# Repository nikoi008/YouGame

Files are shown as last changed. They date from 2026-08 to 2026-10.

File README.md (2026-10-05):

# YouGame!

## What is it? 
YouGame is a handheld device designed for making games using the tft adruino library!

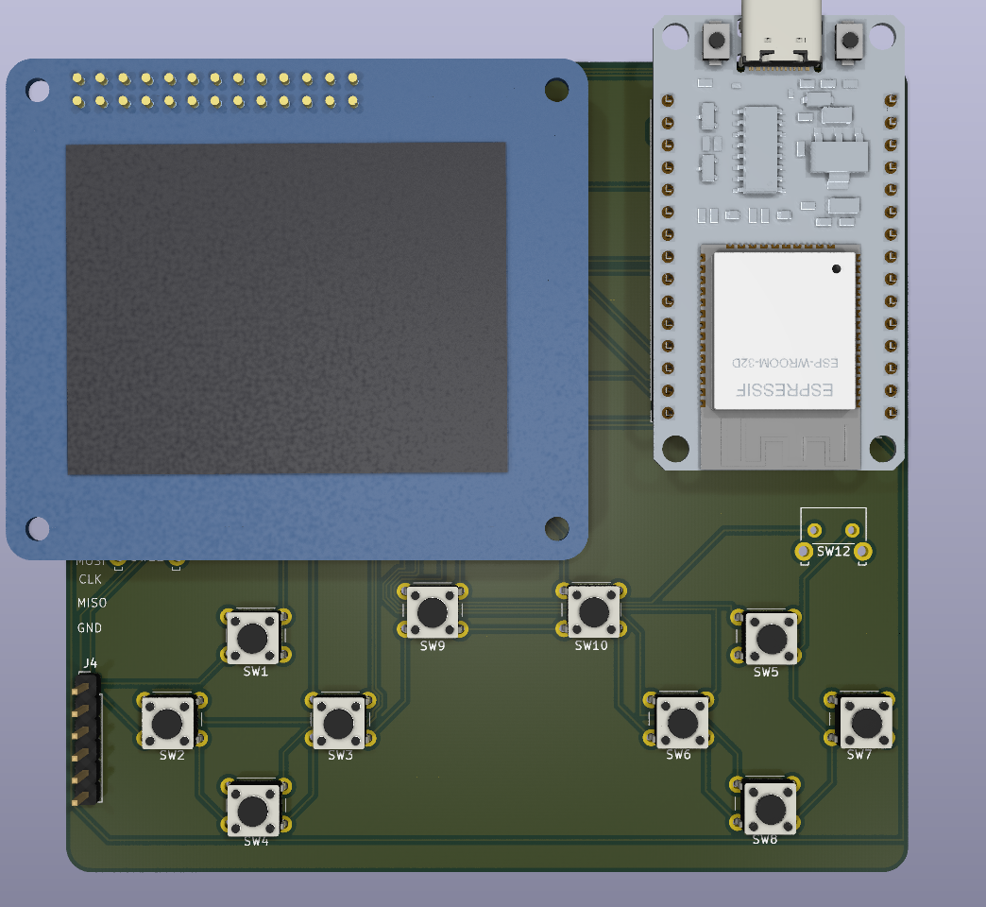
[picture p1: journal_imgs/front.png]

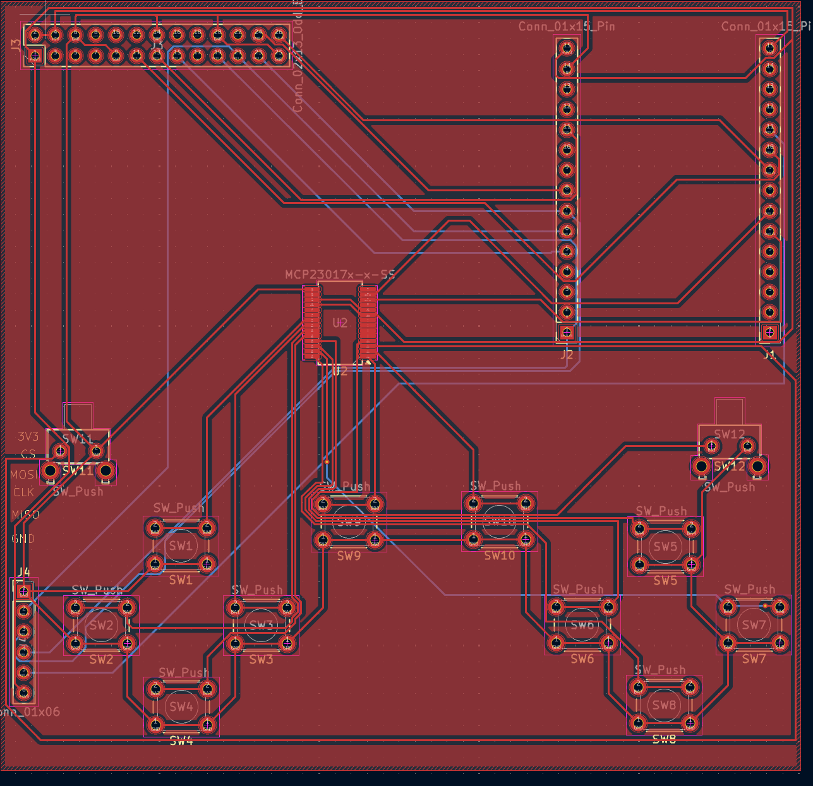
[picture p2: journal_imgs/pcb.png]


## Features
12 Buttons -- 10 normal push buttons and 2 shoulder trigger style buttons  
320x240 LCD screen  
SD card slot to store the games on an sd card  
ESP32 S3 as the brains  

## Why was this made?  
I mainly decided to do this since I had an old raspberry pi screen that i thought was fried. Since i didn't have my pi on me, I decided to use my esp32 to see if it was. After a while of figuring out which pin goes where, i finally managed to turn on the backlight, and then got images displaying on it! After that i had the idea to turn it into something more than just making it work, so I decided to use it for my second ever hardware project. Along the way I figured out how to use SD card modules, used an expansion board which connects all the buttons together, and learned a lot about hardware all together!  

## Building instructions

Its easiest to start with smallest first, so here is how it will go.  

### Sd card module and triggers
The sd card module and the triggers are going to be under the board, so make sure they are connected the right way round

### MCP2017 Expansion board
Get your soldering iron out because thisll have to be hand soldered

### Headers and buttons  
Headers and buttons are all through hole components so it shouldn't be too challenging to solder them through
## BOM

| Item | Qty | Price (USD) | Link |
|---|---|---|---|
| 2.4" Touch Screen SPI TFT LCD | 1 | $10.24 | [Link](https://www.aliexpress.com/item/1005005770033042.html) |
|2x40 Breakable Pin Header 2.54mm Male (10pcs) | 1 | $2.05 | [Link](https://a.aliexpress.com/_EJZPzXy) |
| Momentary Tactile Push Button 6x6x5 Right Angle (20pcs) | 1 | $1.74 | [Link](https://www.aliexpress.com/item/1005006384754591.html) |
| 12x12mm Panel Tactile Switch, H6.5mm (10pcs) — shoulder buttons | 1 | $1.60 | [Link](https://www.aliexpress.com/item/1005006164609617.html) |
| TF Micro SD Card Module (SPI) | 1 | $0.90 | [Link](https://www.aliexpress.com/item/1005005302035188.html) |
| Female Pin Header Socket Gold Plated 15-Pin (10pcs) | 1 | $3.70 | [Link](https://www.aliexpress.com/item/1005003610333849.html) |
| ESP32 WiFi Bluetooth Dev Board Type-C CH340 | 1 | $5.59 | [Link](https://www.aliexpress.com/item/1005008771142129.html) |
| PCB fabrication | 1 | $11.45 | jlcbcp.com  |
| MCP2017-SS expansion baord | 1 | 1.84 | https://www.aliexpress.com/item/1005010450787157.html?mp=1 |

**Total:** $39.1

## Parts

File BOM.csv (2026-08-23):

Item | Qty | Price (USD) | Link
2.4" Touch Screen SPI TFT LCD | 1 | $10.24 | https://www.aliexpress.com/item/1005005770033042.html
2x40 Breakable Pin Header 2.54mm Male (10pcs) | 1 | $2.05 | https://a.aliexpress.com/_EJZPzXy
Momentary Tactile Push Button 6x6x5 Right Angle (20pcs) | 1 | $1.74 | https://www.aliexpress.com/item/1005006384754591.html
12x12mm Panel Tactile Switch, H6.5mm (10pcs) — shoulder buttons | 1 | $1.60 | https://www.aliexpress.com/item/1005006164609617.html
TF Micro SD Card Module (SPI) | 1 | $0.90 | https://www.aliexpress.com/item/1005005302035188.html
Female Pin Header Socket Gold Plated 15-Pin (10pcs) | 1 | $3.70 | https://www.aliexpress.com/item/1005003610333849.html
ESP32 WiFi Bluetooth Dev Board Type-C CH340 | 1 | $5.59 | https://www.aliexpress.com/item/1005008771142129.html
PCB fabrication | 1 | $9.03 | jlcbcp.com

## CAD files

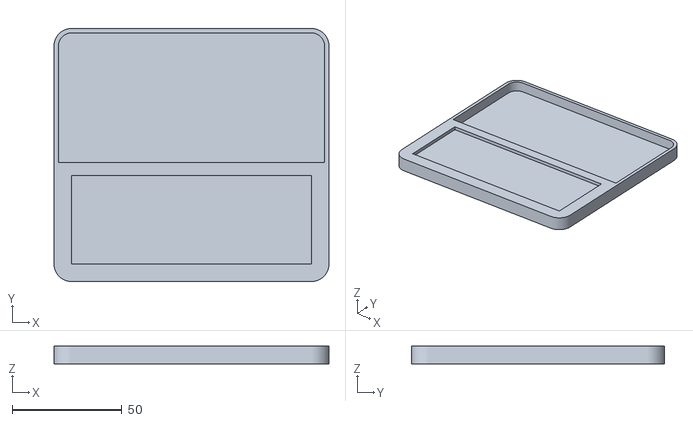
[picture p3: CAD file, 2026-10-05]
3d models/CASE.stl
125.0 x 115.0 x 8.00

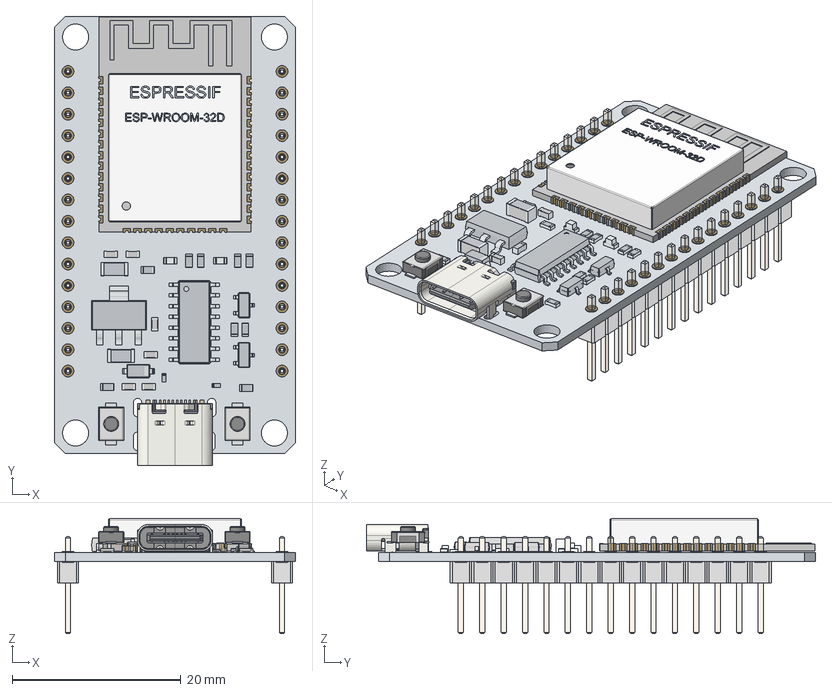
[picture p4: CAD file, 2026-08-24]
pcb/esp32.step
28.6 x 53.3 x 13.7 mm
PCB
SOIC_16_39x99mm_P127mm
SOT_223
USB_C_Receptacle_16P_TopMnt_Horizontal_GCT_USB4105-xx-A
USB_C_Receptacle_16P_TopMnt_Horizontal_GCT_USB4105-xx-A001
USB_C_Receptacle_16P_TopMnt_Horizontal_GCT_USB4105-xx-A002
USB_C_Receptacle_16P_TopMnt_Horizontal_GCT_USB4105-xx-A003
USB_C_Receptacle_16P_TopMnt_Horizontal_GCT_USB4105-xx-A004
USB_C_Receptacle_16P_TopMnt_Horizontal_GCT_USB4105-xx-A005
USB_C_Receptacle_16P_TopMnt_Horizontal_GCT_USB4105-xx-A006
USB_C_Receptacle_16P_TopMnt_Horizontal_GCT_USB4105-xx-A007
USB_C_Receptacle_16P_TopMnt_Horizontal_GCT_USB4105-xx-A008
USB_C_Receptacle_16P_TopMnt_Horizontal_GCT_USB4105-xx-A009
USB_C_Receptacle_16P_TopMnt_Horizontal_GCT_USB4105-xx-A010
USB_C_Receptacle_16P_TopMnt_Horizontal_GCT_USB4105-xx-A011
USB_C_Receptacle_16P_TopMnt_Horizontal_GCT_USB4105-xx-A012
USB_C_Receptacle_16P_TopMnt_Horizontal_GCT_USB4105-xx-A013
USB_C_Receptacle_16P_TopMnt_Horizontal_GCT_USB4105-xx-A014
USB_C_Receptacle_16P_TopMnt_Horizontal_GCT_USB4105-xx-A015
USB_C_Receptacle_16P_TopMnt_Horizontal_GCT_USB4105-xx-A016
USB_C_Receptacle_16P_TopMnt_Horizontal_GCT_USB4105-xx-A017
USB_C_Receptacle_16P_TopMnt_Horizontal_GCT_USB4105-xx-A018
USB_C_Receptacle_16P_TopMnt_Horizontal_GCT_USB4105-xx-A019
USB_C_Receptacle_16P_TopMnt_Horizontal_GCT_USB4105-xx-A020
USB_C_Receptacle_16P_TopMnt_Horizontal_GCT_USB4105-xx-A021
USB_C_Receptacle_16P_TopMnt_Horizontal_GCT_USB4105-xx-A022
USB_C_Receptacle_16P_TopMnt_Horizontal_GCT_USB4105-xx-A023
USB_C_Receptacle_16P_TopMnt_Horizontal_GCT_USB4105-xx-A024
USB_C_Receptacle_16P_TopMnt_Horizontal_GCT_USB4105-xx-A025
USB_C_Receptacle_16P_TopMnt_Horizontal_GCT_USB4105-xx-A026
USB_C_Receptacle_16P_TopMnt_Horizontal_GCT_USB4105-xx-A027
USB_C_Receptacle_16P_TopMnt_Horizontal_GCT_USB4105-xx-A028
USB_C_Receptacle_16P_TopMnt_Horizontal_GCT_USB4105-xx-A029
USB_C_Receptacle_16P_TopMnt_Horizontal_GCT_USB4105-xx-A030
USB_C_Receptacle_16P_TopMnt_Horizontal_GCT_USB4105-xx-A031
USB_C_Receptacle_16P_TopMnt_Horizontal_GCT_USB4105-xx-A032
USB_C_Receptacle_16P_TopMnt_Horizontal_GCT_USB4105-xx-A033
USB_C_Receptacle_16P_TopMnt_Horizontal_GCT_USB4105-xx-A034
USB_C_Receptacle_16P_TopMnt_Horizontal_GCT_USB4105-xx-A035
LED_0603_D2
LED_0603_PWR
SOT_23_1
SOT_23_002
D_SOD_123
R_0603_
R_0603_001
R_0603_002
R_0603_003
R_0603_004
R_0603_005
R_0603_006
R_0603_007
R_0402_001
R_0402_002
R_0603_008
C_0603_
C_0603_001
C_0603_002
C_0603_003
C_0603_004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

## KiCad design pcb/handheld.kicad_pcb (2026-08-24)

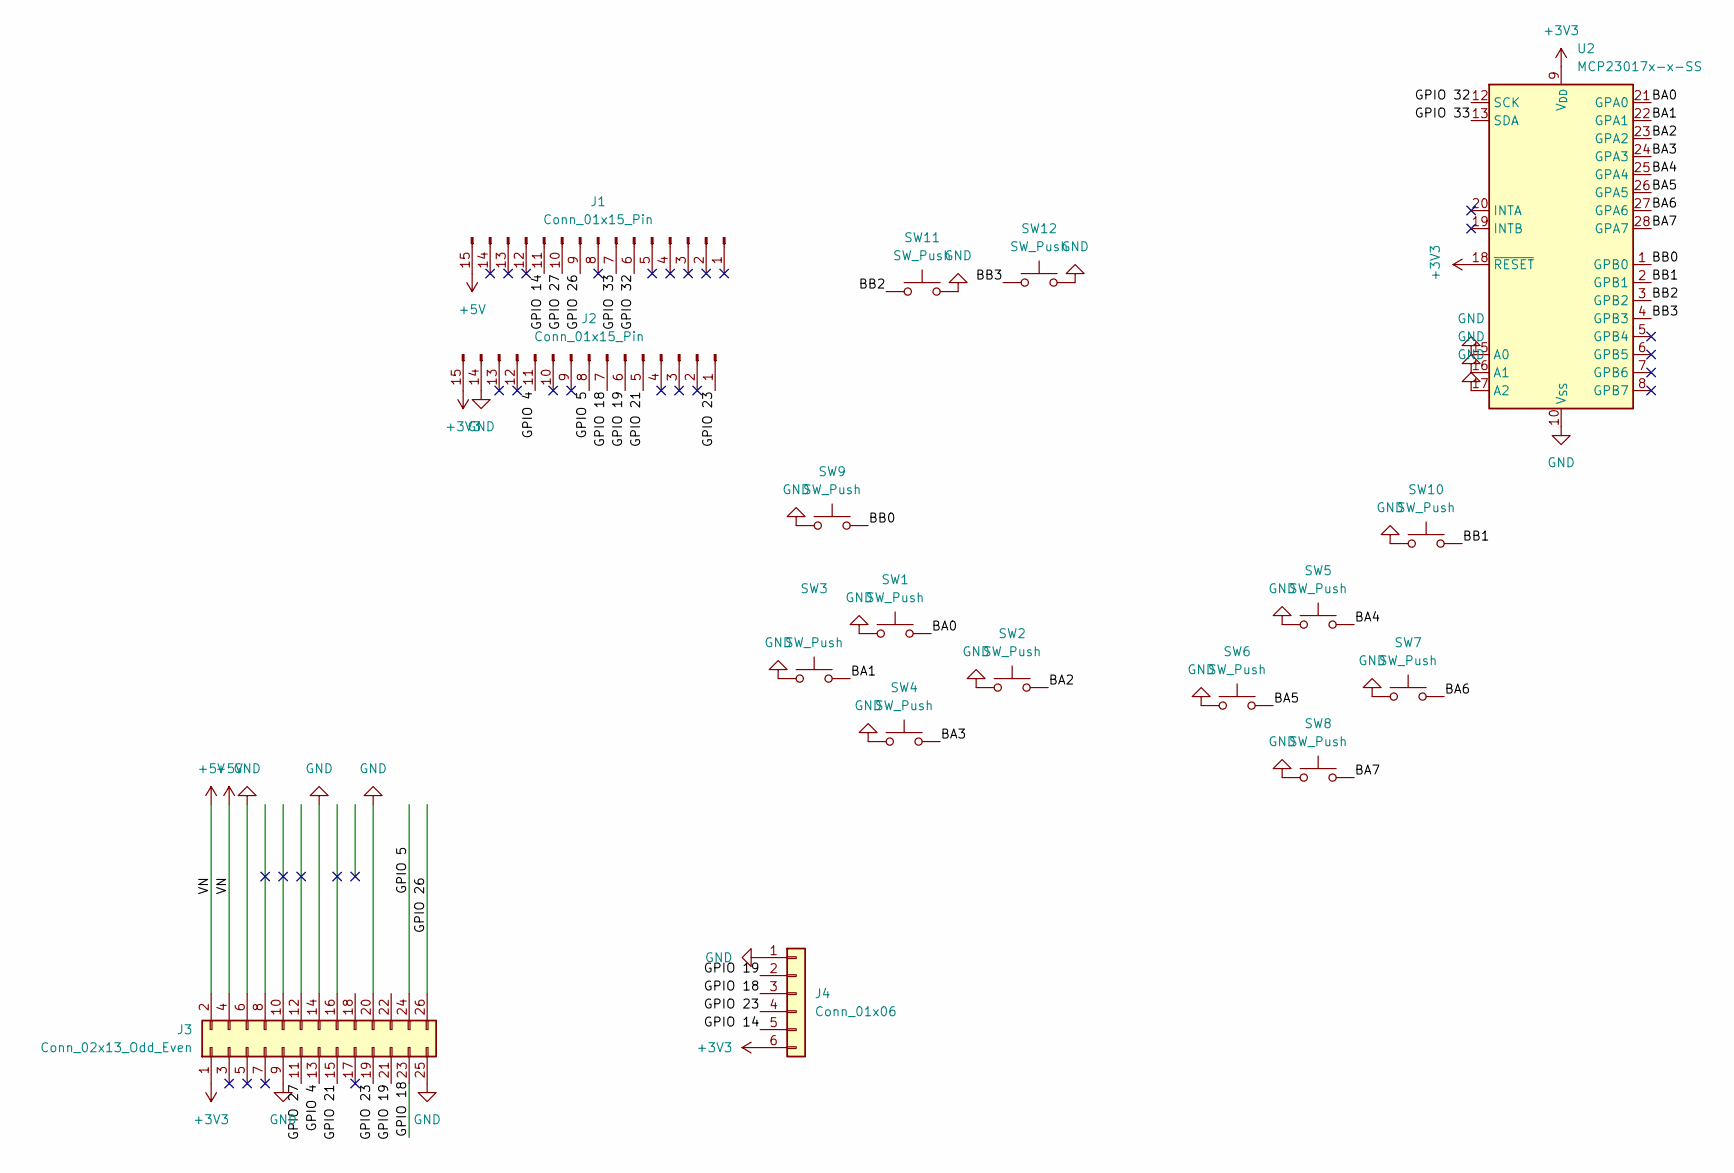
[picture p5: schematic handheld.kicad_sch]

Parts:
J1, J2: Conn_01x15_Pin; PinSocket_1x15_P2.54mm_Vertical
J3: Conn_02x13_Odd_Even; PinHeader_2x13_P2.54mm_Vertical
J4: Conn_01x06; PinHeader_1x06_P2.54mm_Vertical
SW1, SW2, SW3, SW4, SW5, SW6, SW7, SW8, SW9, SW10: SW_Push; SW_PUSH_6mm
SW11, SW12: SW_Push; SW_Tactile_SKHH_Angled
U2: MCP23017x-x-SS; SSOP-28_5.3x10.2mm_P0.65mm

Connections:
+3V3: J2.15, J3.1, J4.6, U2.9 (V_{DD}), U2.18 (~RESET)
+5V: J1.15, J3.2, J3.4
/BA0: SW1.2, U2.21 (GPA0)
/BA1: SW3.2, U2.22 (GPA1)
/BA2: SW2.2, U2.23 (GPA2)
/BA3: SW4.2, U2.24 (GPA3)
/BA4: SW5.2, U2.25 (GPA4)
/BA5: SW6.2, U2.26 (GPA5)
/BA6: SW7.2, U2.27 (GPA6)
/BA7: SW8.2, U2.28 (GPA7)
/BB0: SW9.2, U2.1 (GPB0)
/BB1: SW10.2, U2.2 (GPB1)
/BB2: SW11.1, U2.3 (GPB2)
/BB3: SW12.1, U2.4 (GPB3)
/GPIO 4: J2.11, J3.13
/GPIO 5: J2.8, J3.24
/GPIO 14: J1.11, J4.5
/GPIO 18: J2.7, J3.23, J4.3
/GPIO 19: J2.6, J3.21, J4.2
/GPIO 21: J2.5, J3.15
/GPIO 23: J2.1, J3.19, J4.4
/GPIO 26: J1.9, J3.26
/GPIO 27: J1.10, J3.11
/GPIO 32: J1.6, U2.12 (SCK)
/GPIO 33: J1.7, U2.13 (SDA)
GND: J2.14, J3.6, J3.9, J3.14, J3.20, J3.25, J4.1, SW1.1, SW2.1, SW3.1, SW4.1, SW5.1, SW6.1, SW7.1, SW8.1, SW9.1, SW10.1, SW11.2, SW12.2, U2.10 (V_{SS}), U2.15 (A0), U2.16 (A1), U2.17 (A2)

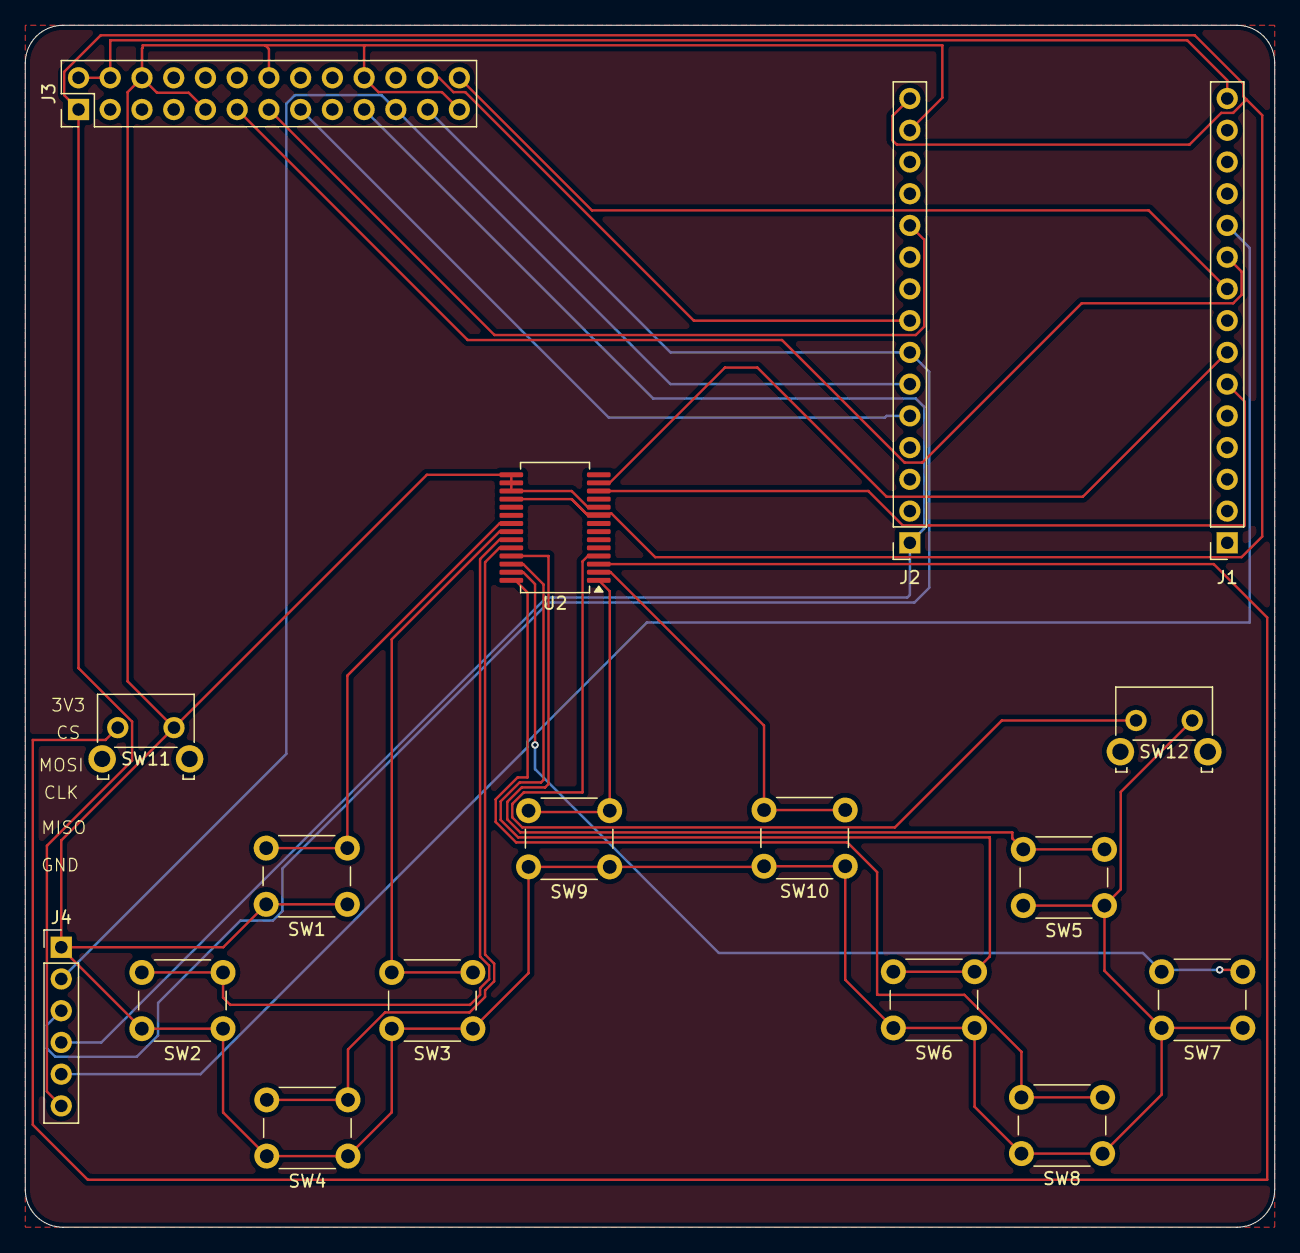
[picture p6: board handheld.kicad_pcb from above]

Board: 2 copper layers, 100.0 x 96.2 mm, 17 parts (0 on the bottom side), 26 nets.

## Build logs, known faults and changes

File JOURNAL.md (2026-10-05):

---
title: "YouGame"
author: "Nicholas Soukmandjiev"
description: "YouGame is a small usb powered handheld console using an old raspberry pi screen and an esp32"
created_at: "2026-04-19"
---

# April 19: Got the raspberry pi screen to work on the esp32!

I first isolated all the pins that were needed to actually power on the lcd as well as looked at the docs (https://www.lcdwiki.com/2.4inch_RPi_Display_For_RPi_3A%2B)

Then i matched the correct pins and used the tft library, and it worked like a charm!!

Heres a picture of it displaying a cat
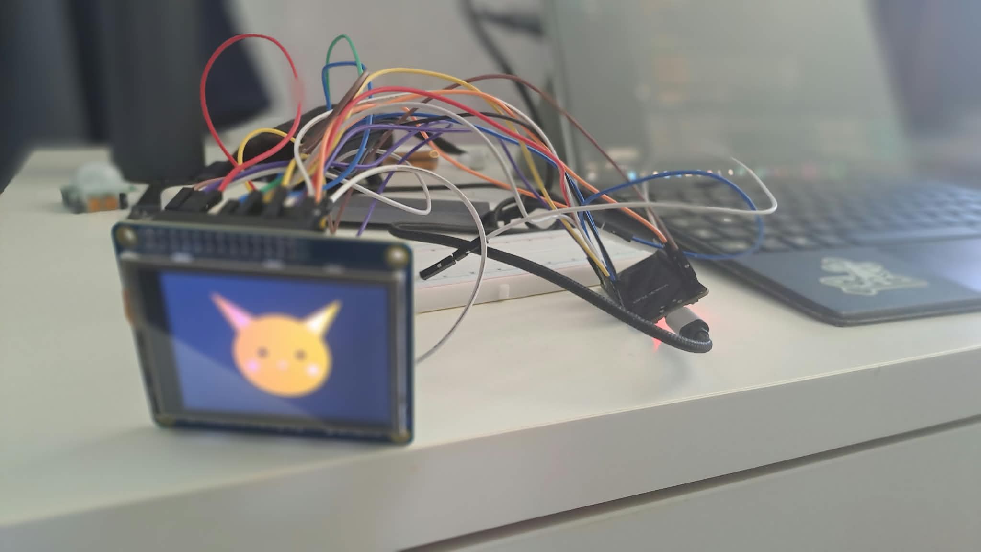
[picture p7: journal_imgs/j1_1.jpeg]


**Total time spent: 2 hours**

# April 19: Made the schematic for the handheld

This was the first time i used a lot of these components, so i was quite confused, however we made it out alive!

I connected the screen to the esp32, then used an expansion board to wire up all of the buttons to it!

I also decided to add an sd card module to eventually add games to it!

it has 10 normal buttons and 2 trigger style buttons!

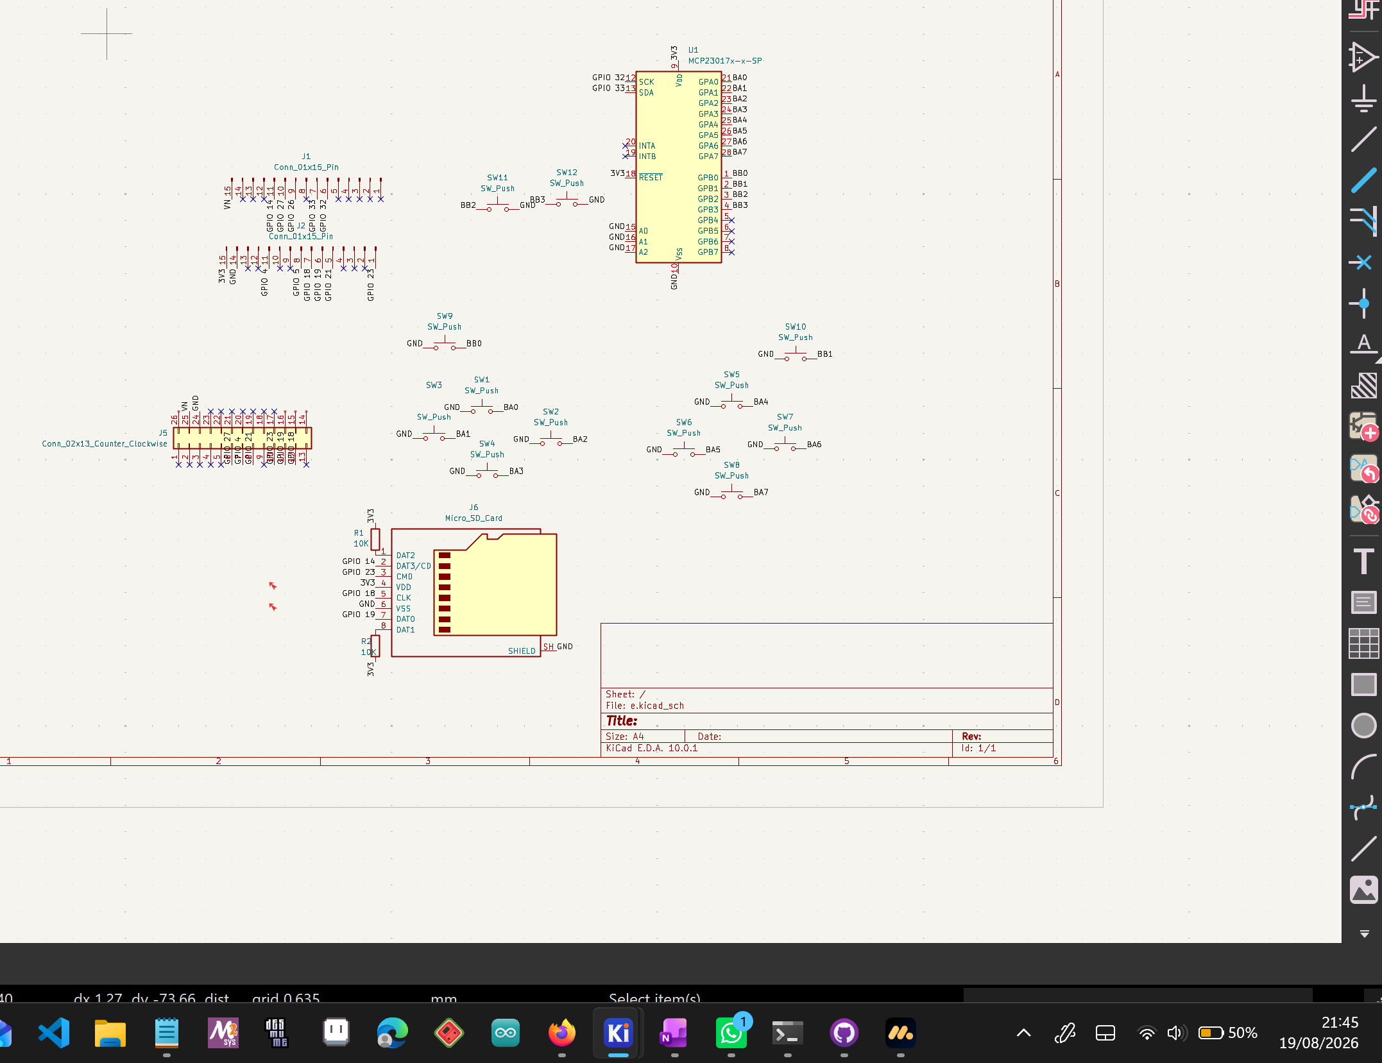
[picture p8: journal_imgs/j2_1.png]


**Total time spent: 2.5 hours**

# April 19: Designed the board

I approximated all the measurements since i dont have calipers, but there is enough space for everything to fit properly!

Time to route!!

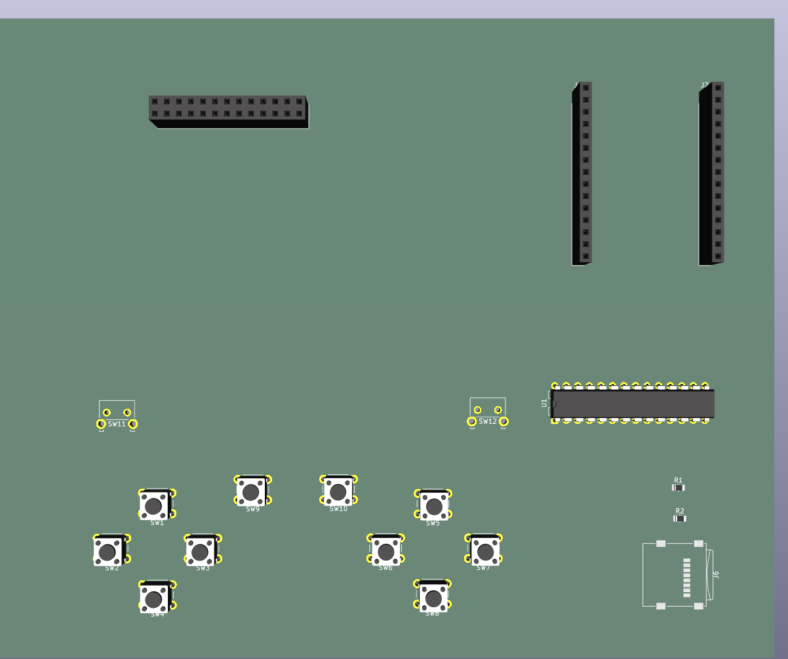
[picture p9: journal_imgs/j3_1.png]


**Total time spent: 1 hour**

# April 19: Routed the PCB!

This was the first time i had used vias, and they made routing a bit easier, but routing this was still very difficult for me. In the end however, it turned out pretty good and now its time to add a silkscreen!!!

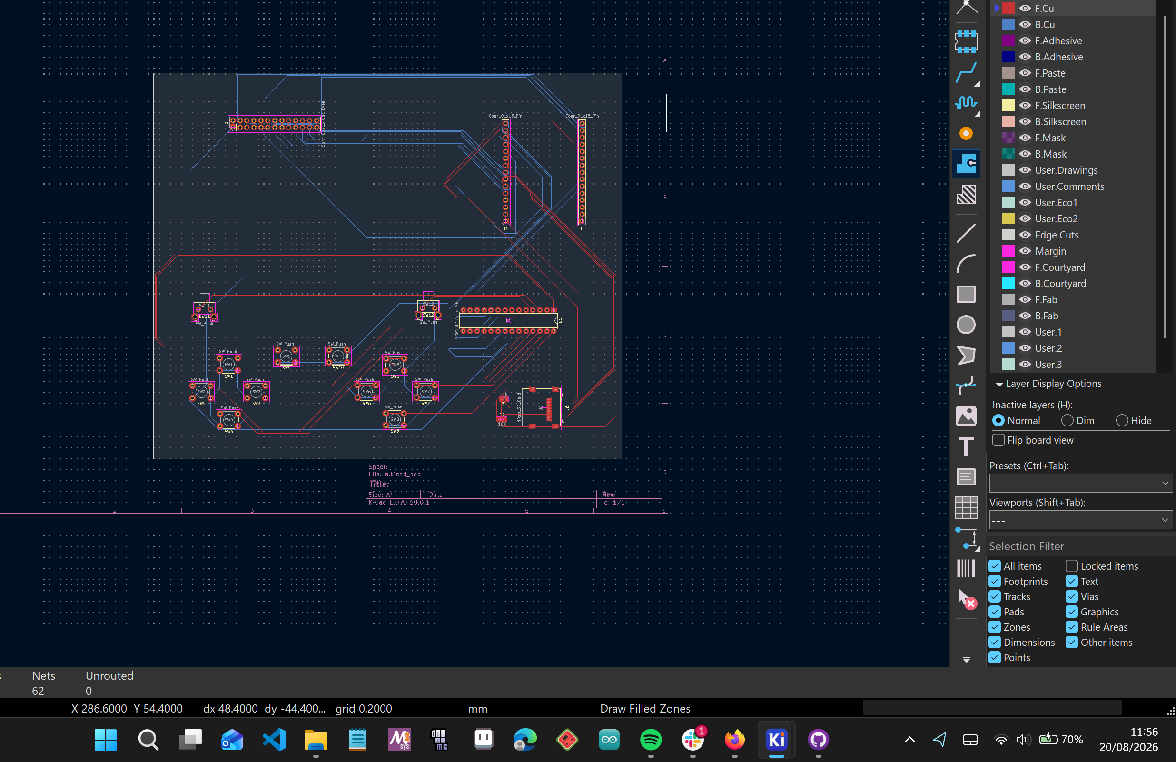
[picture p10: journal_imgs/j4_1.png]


**Total time spent: 4.5 hours**

# April 19: Silkscreen!

I took a few designs from the hc sticker catalogue and added them to the screen! I also put a qr code of my repo there

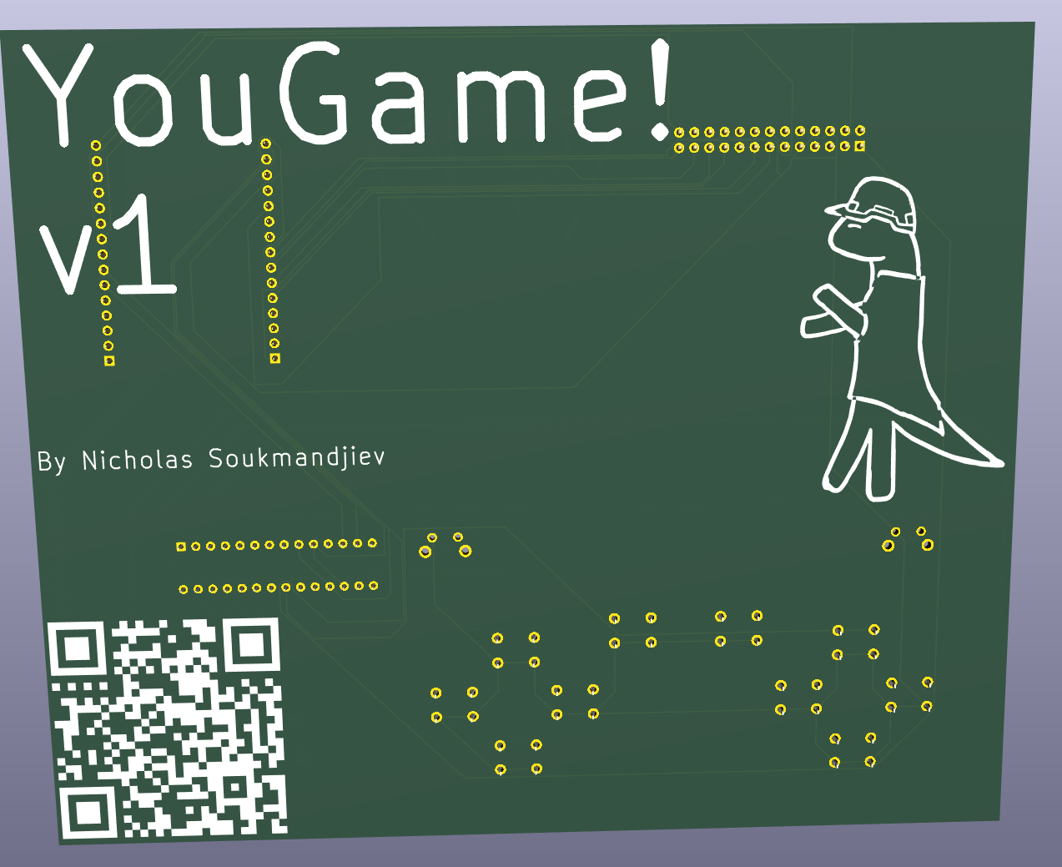
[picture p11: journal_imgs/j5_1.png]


**Total time spent: 0.5 hours**

# April 19: Final bits of polish -- BOM, Journal and traces

I got all of the parts off of aliexpress and put them into a bom

However the sd card module i was getting was different from the one on my pcb so i had to change it to a different one

I also polished up a few funky looking traces and now im done with the pcb!

Then I made this journal and am now going to make the readme and ship!!

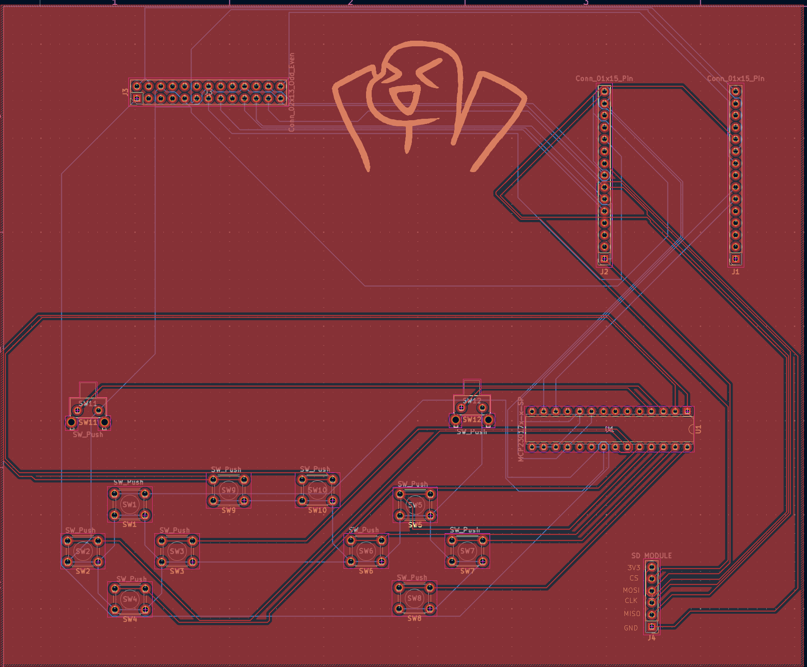
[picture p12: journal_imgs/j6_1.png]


**Total time spent: 1.5 hours**

# April 24: Remade everything to fit in a 100x100mm pcb

This was fun but really annoying since the spacing was really tight, but I feel like it all works now and im glad with the end result. I had to redo it twice though since my first version was like 112mm,which was annoying. I also modelled the screen and found the esp32 model online since i was forced to have in speedrun. I did write this long after since i got really burnt out after some issues with this project so i dont remember everything fully



**Total time spent: 4 hours**

# September 10: made the case

Yes, I finally did it! Its bad but this is the most of my cad skills. the thing im proud of most is that it is literally 1 piece so there is no need for assembly!  
Btw when I say this took ages, I MEAN it. the sheer amount of unclosed wire errors I got were ridiculous. Eventually I figured out how they were caused by, but now it REALLY is time to submit

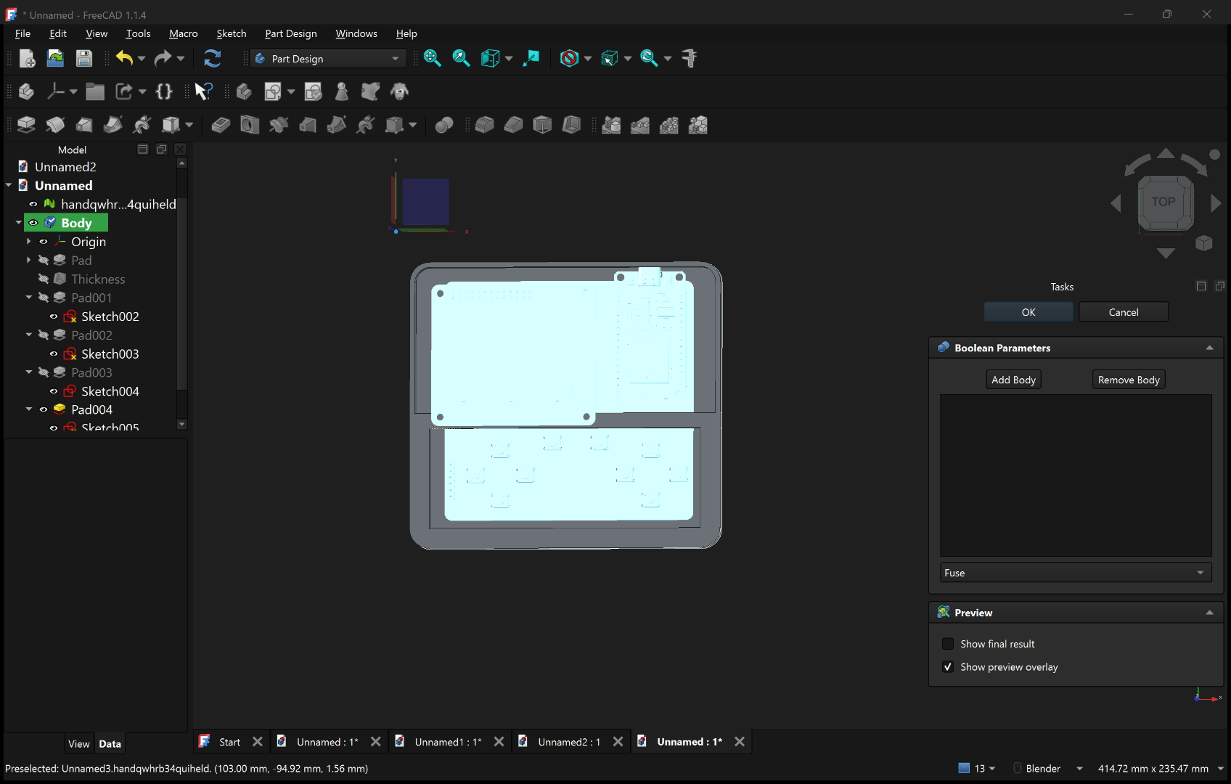
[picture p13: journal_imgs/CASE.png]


**Total time spent: 3 hours**

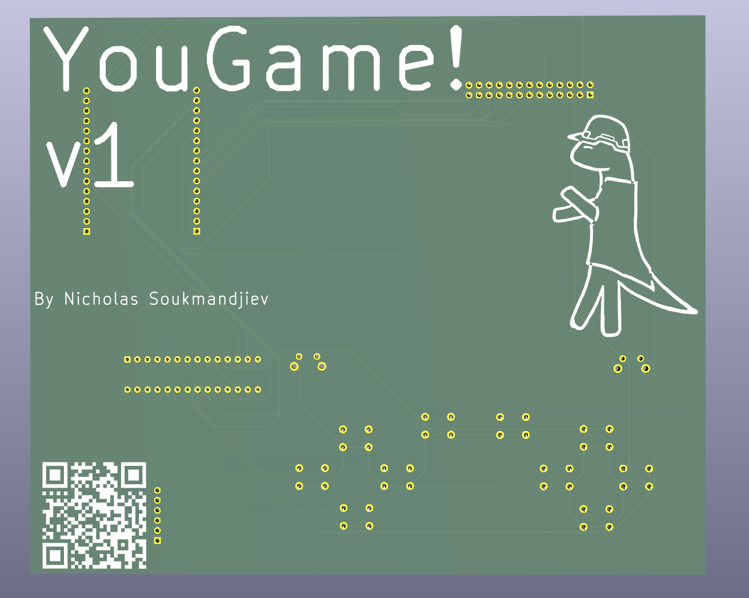
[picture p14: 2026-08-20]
journal_imgs/j6_3.png

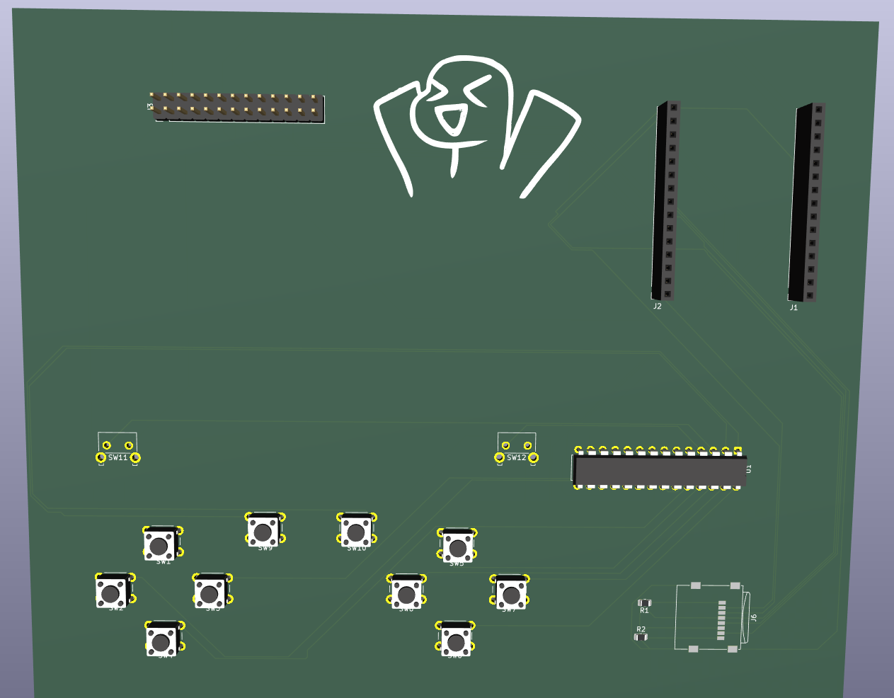
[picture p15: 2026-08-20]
journal_imgs/j5_2.png

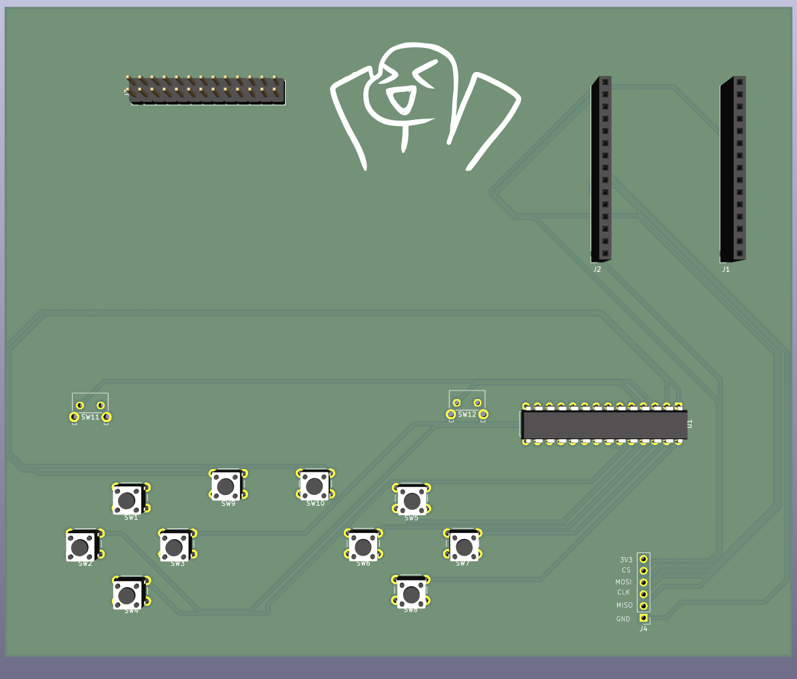
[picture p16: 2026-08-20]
journal_imgs/j6_2.png

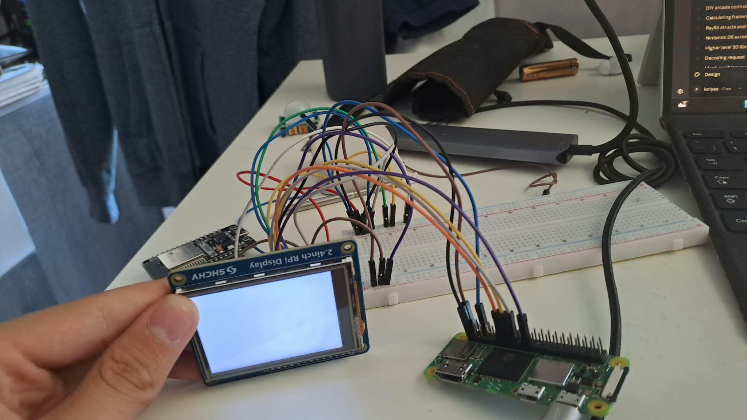
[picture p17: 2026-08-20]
journal_imgs/image.png

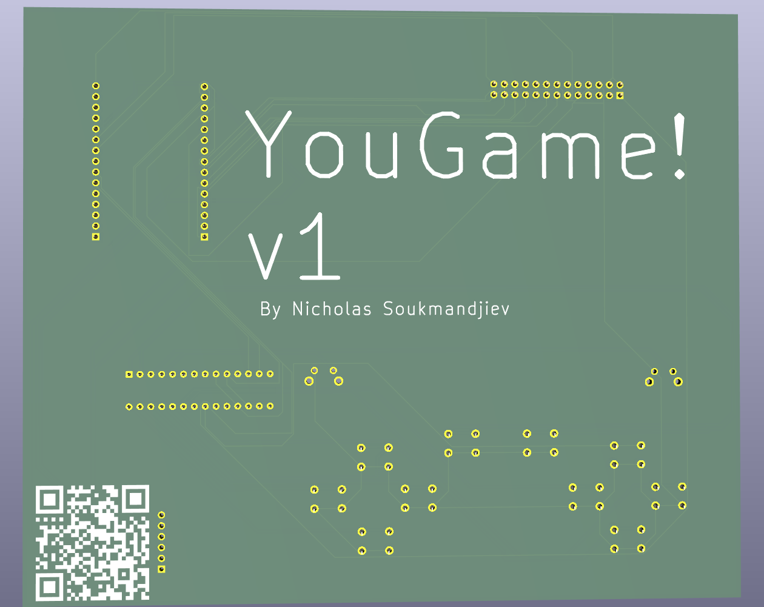
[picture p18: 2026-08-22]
journal_imgs/back.png

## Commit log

2026-08-20 pcb and schematic
    [e.dsn, e.kicad_pcb, e.kicad_sch]
2026-08-20 final pcb and schematic
    [e.dsn, e.kicad_pcb, handheld.kicad_pcb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]
2026-08-20 updated sd card module
    https://www.aliexpress.com/item/1005005302035188.html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
    [handheld.kicad_pcb]
2026-08-20 final pcb
    [handheld.kicad_pcb, handheld.kicad_sch]
2026-08-20 unpopulated sd card module pins
    [handheld.kicad_pcb]
2026-08-20 put all pcb stuff in a pcb folder
    [handheld.kicad_pcb, handheld.kicad_sch]
2026-08-22 udpated imgs, correct distance between headers
    [handheld.kicad_pcb]
2026-08-23 updated readme and bom
    [BOM.csv]
2026-08-24 3d models
    [esp32.step, handheld.kicad_pcb]
2026-08-24 rounded corners
    [handheld.kicad_pcb]
